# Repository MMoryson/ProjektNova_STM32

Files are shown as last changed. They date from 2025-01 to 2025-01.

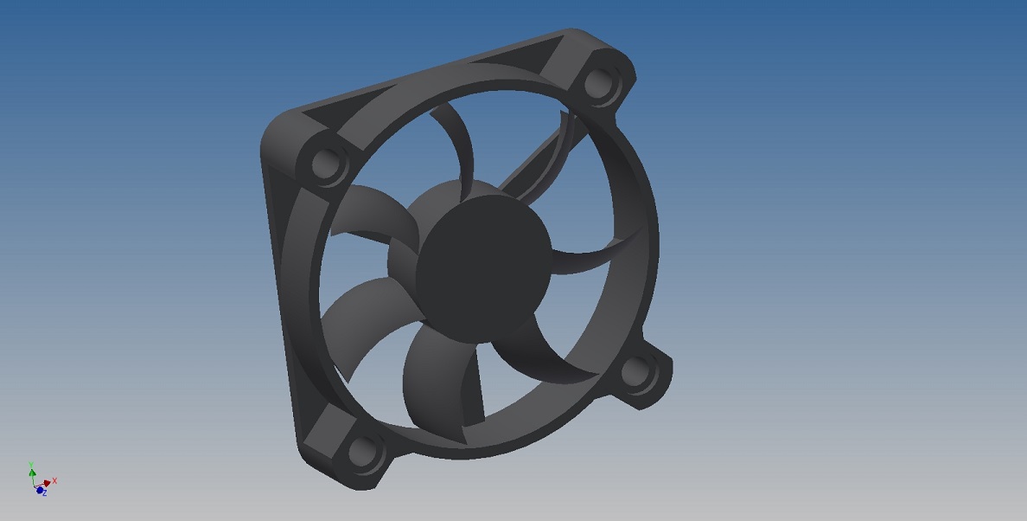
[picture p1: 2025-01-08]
Projekt_STM_model_Inventor/50-mm-dc-fan-1.snapshot.2/JAMICO FAN 50X50X10.jpg

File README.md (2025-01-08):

# ProjektNova_STM32
Jest to projekt na zajęcia z Systemów Mikroprocesorowych w ramach studiów Automatyka i Robotyka na Politechnice Poznańskiej

Projekt ma na celu stowrzenia układu sterowania wysokością piłeczki ping pongowej w tubie za pomocą wiatraka.

Projekt jest stworzony na płytce NUCLEO-F746ZG (z mikrokontrolerem STM32F746ZG)
Użyte elementy:
- enkoder inkrementalny (20 impulsów na obrót)
- wyświetlacz ssd1306 oled komunikujący się za pomocą I2C 
- ultradźwiękowy hc-sr04
- tranzystor n mosfet tht irl540npbf (100 Vds)
- wiatrak (50x50mm, Napięcie: DC 5-12V, Prąd: 0.3A, RPM(11.1V): 3500, 50x50x10mm, 20g)
- zasilacz (9V/0.6A)
- kondensatory 10nF
- reyzstory 1.1 kOhmów i 10 kOhmów
- przewody

Projekt używa biblioteki z własnymi modyfikacjami do wyświetlacza ssd1306 zaczerpniętej z: https://github.com/ptrre/kurs-stm32-e18-oled-i2c .

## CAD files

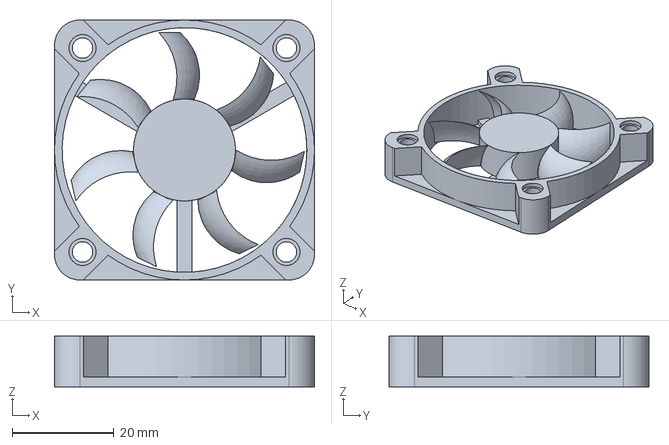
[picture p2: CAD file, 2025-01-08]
Projekt_STM_model_Inventor/50-mm-dc-fan-1.snapshot.2/JAMICO FAN 50X50X10.stp
51.0 x 51.0 x 10.0 mm

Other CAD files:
Projekt_STM_model_Inventor/50-mm-dc-fan-1.snapshot.2/JAMICO FAN 50X50X10.igs
Projekt_STM_model_Inventor/50-mm-dc-fan-1.snapshot.2/JAMICO FAN 50X50X10.ipt
Projekt_STM_model_Inventor/50-mm-dc-fan-1.snapshot.2/JAMICO FAN 50X50X10.x_b
Projekt_STM_model_Inventor/Calosc.iam
Projekt_STM_model_Inventor/CzujnikUltraDziekowy.iam
Projekt_STM_model_Inventor/enkoder.ipt

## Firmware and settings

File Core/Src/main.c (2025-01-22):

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
/* Includes ------------------------------------------------------------------*/
#include "main.h"
#include "dma.h"
#include "i2c.h"
#include "tim.h"
#include "usart.h"
#include "usb_otg.h"
#include "gpio.h"

/* USER CODE BEGIN Includes */
/*
 * Jest to regulator PI wiec:
 * sygnal refenercyjny - 	czyjnik			- dystans
 * sygnal wejsciowy - 		enkoder			- pozycja
 * sygnal wyjsciowy - 		wypelnienie pwm - wypelnienie
 */

#include <stdio.h>
#include <string.h>
#include "GFX.h"
#include "bitmapy.h"
#include "i2c_connection.h"
/* USER CODE END Includes */


/* USER CODE BEGIN PV */
uint8_t znak, komunikat[20];
uint16_t dl_kom;

//uint16_t wypelnienie = 0;
//temp
float wypelnienie = 0.0;
uint8_t pwm_send = 0;

char msg[64];

uint32_t counter;
int16_t count;
int16_t pozycja = 20;
int16_t pozycja_send=20;

char msg_dyst[64];
uint32_t pMillis;
uint32_t Value1 = 0;
uint32_t Value2 = 0;
uint16_t dystans  = 0;
uint16_t dystans_temp = 0;

uint32_t previousTime = 0;

typedef struct {
    float Kp;      // Wzmocnienie proporcjonalne
    float Ki;      // Wzmocnienie całkujące
    float calka; // Skumulowany błąd
    float zadana; // Wartość zadana
} Reg_PI;

Reg_PI nasz_PI = {
    .Kp = 13.5f,  // Ustawienia wzmocnienia
    .Ki = 0.48f,
    .calka = 0.0f,
    .zadana = 0.0f // Przykładowa wartość zadana
};

float dt = 0.0001f;
float wynik;
float wynik_temp;
float uchyb;
int ograniczenie_calki = 40;


/* USER CODE END PV */

void SystemClock_Config(void);
/* USER CODE BEGIN 0 */

void HAL_GPIO_EXTI_Callback(uint16_t GPIO_Pin)
{
	if(GPIO_Pin == P2_Pin)
	{
		HAL_GPIO_TogglePin(LD1_GPIO_Port, LD1_Pin);
		pozycja = pozycja_send;

		if (!stan_rozpoczecia_inwersji)
		{
			stan_rozpoczecia_inwersji = true;
			odliczenie_inwersji = HAL_GetTick();
			licznik_migniec = 0;
			stan_inwersji = false;
		}


		//SSD1306_display_invert(true);
		//HAL_Delay(10);
		//SSD1306_display_invert(false);
	}
	if (GPIO_Pin == Echo_Pin)
	{
		pMillis = HAL_GetTick();
		while (!(HAL_GPIO_ReadPin (Echo_GPIO_Port, Echo_Pin)) && pMillis + 10 >  HAL_GetTick());
		Value1 = __HAL_TIM_GET_COUNTER (&htim4);

		pMillis = HAL_GetTick();
		while ((HAL_GPIO_ReadPin (Echo_GPIO_Port, Echo_Pin)) && pMillis + 50 > HAL_GetTick());
		Value2 = __HAL_TIM_GET_COUNTER (&htim4);
		dystans_temp = 100 - (Value2-Value1)* 0.034/2;

		dystans = saturacja(dystans_temp, 0, 90);


		//dystans = dystans_temp;




		/*if(abs(dystans_temp - dystans)>100)
		{
			dystans = saturacja(dystans, 10, 100);
		}
		else{
			dystans = saturacja(dystans_temp, 10, 100);
		}*/

		/*
		int tx_msg_len_tim = sprintf((char *)msg_dyst, "dystans: %d cm\r\n", dystans);
		HAL_UART_Transmit(&huart3, (uint8_t *)msg_dyst, tx_msg_len_tim, 100);
		*/

	 }

}

void HAL_UART_RxCpltCallback(UART_HandleTypeDef *huart)
{
	if(huart->Instance == USART3)
	{

		int enkoder = strtol((char*)&znak, 0, 10);
		pozycja = saturacja(enkoder, 20, 100);
		pozycja_send = pozycja;

		//HAL_UART_Transmit_IT(&huart3, komunikat, dl_kom);
		HAL_UART_Receive_IT(&huart3, &znak, 3);

	}
}

int wrap_encoder(int count, int min, int max, int shift, TIM_HandleTypeDef *htim)
{
    if (count < min * 4) {
        count += (max - min) * 4;
        __HAL_TIM_SET_COUNTER(htim, count);
        return min;
    }
    if (count > max * 4) {
        count -= (max - min) * 4;
        __HAL_TIM_SET_COUNTER(htim, count);
        return max;
    }
    return count / 4 + shift;
}

void HAL_TIM_IC_CaptureCallback(TIM_HandleTypeDef *htim)
{

	//static uint32_t last_send_time = 0;

	counter = __HAL_TIM_GET_COUNTER(&htim3);
	count = (int16_t)counter;

	pozycja_send = wrap_encoder(count, 0, 80, 20, &htim3);

	/*if (HAL_GetTick() - last_send_time >= 100)
	{
		last_send_time = HAL_GetTick();
		uint8_t tx_buffer[32];
		int tx_msg_len = sprintf((char*)tx_buffer, "Encoder counter: %d\n\r", pozycja);
		HAL_UART_Transmit(&huart3, tx_buffer, tx_msg_len, 100);
	}*/

}

void czujnik_wysylanie(int time)
{
	HAL_GPIO_WritePin(Trigger_GPIO_Port, Trigger_Pin, GPIO_PIN_SET);
	__HAL_TIM_SET_COUNTER(&htim4, 0);
	while (__HAL_TIM_GET_COUNTER(&htim4) < time);
	HAL_GPIO_WritePin(Trigger_GPIO_Port, Trigger_Pin, GPIO_PIN_RESET);
}

int saturacja(int wartosc, int min, int max)
{

	if(wartosc > max)
	{
		wartosc = max;
	}
	if(wartosc < min)
	{
		wartosc = min;
	}
	return wartosc;
}

float obliczanie_PI(Reg_PI *regulator, float dystans, float dt, int ograniczenie) {
    // Obliczanie błędu
    uchyb = regulator->zadana - dystans;

    // Część całkująca
    regulator->calka += uchyb*dt;

    float P = regulator->Kp * uchyb;
    float I;
/*
    if (100*abs(uchyb)/regulator->zadana > ograniczenie)
    {
    	regulator->calka= 0;
    }
*/
    I = regulator->Ki * regulator->calka;

    return  P+I;
}

void HAL_TIM_PeriodElapsedCallback(TIM_HandleTypeDef *htim)
{
	if(htim == &htim14)
	{
		czujnik_wysylanie(10);
		nasz_PI.zadana = pozycja;
		wynik_temp = saturacja(obliczanie_PI(&nasz_PI, (float)dystans, dt, ograniczenie_calki),0, 999)+430.0f;

		wynik = saturacja(wynik_temp, 000, 999);
		wypelnienie = (uint16_t)wynik;
		pwm_send = (uint8_t)(100*wynik/999);
		__HAL_TIM_SET_COMPARE(&htim2, TIM_CHANNEL_1, wypelnienie);


	 	/*wypelnienie = 464;

		if( wypelnienie == 0){flag = 0;}
		if( wypelnienie == 998){flag = 1;}
		if(flag){wypelnienie = wypelnienie - 1;}
		else{wypelnienie = wypelnienie + 1;}
		//wypelnienie = wypelnienie + 1;
	 	  if (wypelnienie > 998){wypelnienie = 0;}
	 	  __HAL_TIM_SET_COMPARE(&htim2, TIM_CHANNEL_1, (uint16_t)wypelnienie);
	 	 pwm_send = (uint8_t)(100*wypelnienie/999);
	 	 */
	 	  //pwm_send = wypelnienie;

		  //temp
		 //pozycja = 60;
		 //pozycja_send = pozycja;


	}

}

/* USER CODE END 0 */

/**
  * @brief  The application entry point.
  * @retval int
  */
int main(void)
{

  /* USER CODE BEGIN 1 */
	//HAL_Delay(500);
  /* USER CODE END 1 */

  /* MCU Configuration--------------------------------------------------------*/

  /* Reset of all peripherals, Initializes the Flash interface and the Systick. */
  HAL_Init();

  /* Configure the system clock */
  SystemClock_Config();

  /* Initialize all configured peripherals */
  MX_GPIO_Init();
  MX_DMA_Init();
  MX_USART3_UART_Init();
  MX_USB_OTG_FS_PCD_Init();
  MX_TIM2_Init();
  MX_TIM3_Init();
  MX_I2C1_Init();
  MX_TIM4_Init();
  MX_TIM14_Init();
  /* USER CODE BEGIN 2 */
  HAL_UART_Receive_IT(&huart3, &znak, 3);

  HAL_TIM_PWM_Start(&htim2, TIM_CHANNEL_1);


  HAL_TIM_Encoder_Start_IT(&htim3, TIM_CHANNEL_ALL);
  __HAL_TIM_SET_COMPARE(&htim2, TIM_CHANNEL_1, 0);




  SSD1306_init();
  //GFX_draw_fill_rect(0, 0, 2*64, 2*32, BLACK);
  //GFX_draw_fill_rect(64, 32, 64, 32, WHITE);
  //GFX_draw_char(10, 10, 'a', WHITE, BLACK, 2, 2);
  //GFX_draw_string(0, 0, (unsigned char *)"Dupia", WHITE, BLACK, 2,2);
  //SSD1306_display_invert(true);
  //GFX_draw_Bitmap(0, 0, wiatrak1, 128, 64, WHITE, BLACK);
  //GFX_draw_string(0, 0, (unsigned char *)"Dupia", WHITE, BLACK, 2,2);
  //SSD1306_display_repaint();
  HAL_TIM_Base_Start_IT(&htim4);
  HAL_GPIO_WritePin(Trigger_GPIO_Port, Trigger_Pin, GPIO_PIN_RESET);
  HAL_TIM_Base_Start_IT(&htim14);




  /* USER CODE END 2 */

  /* Infinite loop */
  /* USER CODE BEGIN WHILE */
  while (1)
  {



	  inwersja3x();
	  oled(pozycja_send, dystans, pwm_send);


		 if (HAL_GetTick() - previousTime >= 500) // Sprawdź, czy minęło 500 ms
		    {
		        previousTime = HAL_GetTick(); // Zapisz aktualny czas

		        int tx_msg_len = sprintf((char *)msg_dyst, "Distance: %d cm, Pozycja: %d , PWM: %d , Encoder counter: %d \n\r", dystans, pozycja, pwm_send, pozycja_send);
		        HAL_UART_Transmit(&huart3, (uint8_t *)msg_dyst, tx_msg_len, 100);
		    }

		  HAL_Delay(10);


		  /*
		  //PWM
		 	  wypelnienie = wypelnienie + 1;
		 	  if (wypelnienie > 998){wypelnienie = 0;}
		 	  __HAL_TIM_SET_COMPARE(&htim2, TIM_CHANNEL_1, wypelnienie);
		 	  pwm_send = wypelnienie;
		 	  */

		/*
		 		int tx_msg_len_tim = sprintf((char *)msg_dyst, "dystans: %d cm\r\n", dystans);
		HAL_UART_Transmit(&huart3, (uint8_t *)msg_dyst, tx_msg_len_tim, 100);
		 if (HAL_GetTick() - last_send_time >= 100)
		 	{
		 		last_send_time = HAL_GetTick();
		 		uint8_t tx_buffer[32];
		 		int tx_msg_len = sprintf((char*)tx_buffer, "Encoder counter: %d\n\r", pozycja);
		 		HAL_UART_Transmit(&huart3, tx_buffer, tx_msg_len, 100);
		 	}*/


	  /*
	  if(HAL_GPIO_ReadPin(P2_GPIO_Port, P2_Pin))
		 {
			 HAL_Delay(10);
			 HAL_GPIO_TogglePin(LD2_GPIO_Port, LD2_Pin);
		 }
	  */

    /* USER CODE END WHILE */

    /* USER CODE BEGIN 3 */
  }
  /* USER CODE END 3 */
}

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


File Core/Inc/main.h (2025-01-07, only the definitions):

#define MCO_Pin GPIO_PIN_0
#define MCO_GPIO_Port GPIOH
#define RMII_MDC_Pin GPIO_PIN_1
#define RMII_MDC_GPIO_Port GPIOC
#define RMII_REF_CLK_Pin GPIO_PIN_1
#define RMII_REF_CLK_GPIO_Port GPIOA
#define RMII_MDIO_Pin GPIO_PIN_2
#define RMII_MDIO_GPIO_Port GPIOA
#define RMII_CRS_DV_Pin GPIO_PIN_7
#define RMII_CRS_DV_GPIO_Port GPIOA
#define RMII_RXD0_Pin GPIO_PIN_4
#define RMII_RXD0_GPIO_Port GPIOC
#define RMII_RXD1_Pin GPIO_PIN_5
#define RMII_RXD1_GPIO_Port GPIOC
#define LD1_Pin GPIO_PIN_0
#define LD1_GPIO_Port GPIOB
#define Trigger_Pin GPIO_PIN_12
#define Trigger_GPIO_Port GPIOF
#define Echo_Pin GPIO_PIN_13
#define Echo_GPIO_Port GPIOF
#define Echo_EXTI_IRQn EXTI15_10_IRQn
#define RMII_TXD1_Pin GPIO_PIN_13
#define RMII_TXD1_GPIO_Port GPIOB
#define LD3_Pin GPIO_PIN_14
#define LD3_GPIO_Port GPIOB
#define STLK_RX_Pin GPIO_PIN_8
#define STLK_RX_GPIO_Port GPIOD
#define STLK_TX_Pin GPIO_PIN_9
#define STLK_TX_GPIO_Port GPIOD
#define USB_PowerSwitchOn_Pin GPIO_PIN_6
#define USB_PowerSwitchOn_GPIO_Port GPIOG
#define USB_OverCurrent_Pin GPIO_PIN_7
#define USB_OverCurrent_GPIO_Port GPIOG
#define USB_SOF_Pin GPIO_PIN_8
#define USB_SOF_GPIO_Port GPIOA
#define USB_VBUS_Pin GPIO_PIN_9
#define USB_VBUS_GPIO_Port GPIOA
#define USB_ID_Pin GPIO_PIN_10
#define USB_ID_GPIO_Port GPIOA
#define USB_DM_Pin GPIO_PIN_11
#define USB_DM_GPIO_Port GPIOA
#define USB_DP_Pin GPIO_PIN_12
#define USB_DP_GPIO_Port GPIOA
#define TMS_Pin GPIO_PIN_13
#define TMS_GPIO_Port GPIOA
#define TCK_Pin GPIO_PIN_14
#define TCK_GPIO_Port GPIOA
#define P2_Pin GPIO_PIN_7
#define P2_GPIO_Port GPIOD
#define P2_EXTI_IRQn EXTI9_5_IRQn
#define RMII_TX_EN_Pin GPIO_PIN_11
#define RMII_TX_EN_GPIO_Port GPIOG
#define RMII_TXD0_Pin GPIO_PIN_13
#define RMII_TXD0_GPIO_Port GPIOG
#define SW0_Pin GPIO_PIN_3
#define SW0_GPIO_Port GPIOB
#define LD2_Pin GPIO_PIN_7
#define LD2_GPIO_Port GPIOB

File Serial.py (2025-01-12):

import csv
import serial
import re
import time
import matplotlib.pyplot as plt
from collections import deque
import tkinter as tk
from tkinter import messagebox

# Flaga globalna do przerwania pętli
stop_plotting = False

# Funkcja do odczytu danych z UART
def odczyt_uart(csv_plik, port='COM3', baudrate=115200, timeout=1):
    start = time.time()
    ser = serial.Serial(port, baudrate, timeout=timeout)

    with open(csv_plik, mode='w', newline='') as file:
        writer = csv.writer(file)
        writer.writerow(['Czas', 'Dystans', 'Pozycja', 'PWM', 'Enkoder'])

    last_time = -1  # Zmienna do sprawdzania unikalności czasu

    try:
        while True:
            if ser.in_waiting > 0:
                a = round(time.time() - start, 3)  # Zaokrąglanie czasu do 3 miejsc po przecinku
                if a == last_time:
                    continue  # Pomijanie duplikatów czasu
                last_time = a

                line = ser.readline().decode('utf-8', errors='ignore').strip()
                temp = re.findall(r'\d+', line)
                res = list(map(int, temp))
                if temp:
                    dystans = res[0]
                    pozycja = res[1]
                    pwm = res[2]
                    enkoder = res[3]
                    czas = a
                    with open(csv_plik, mode='a', newline='') as file:
                        writer = csv.writer(file)
                        writer.writerow([czas, dystans, pozycja, pwm, enkoder])
                    yield (czas, dystans, pozycja, pwm, enkoder)
    except KeyboardInterrupt:
        print("Zatrzymanie zbierania danych.")
    finally:
        if ser.is_open:
            ser.close()
        print("Zamknięto port UART.")

# Funkcja główna do rysowania wykresu
def plot_data(csv_plik, plot_dystans, plot_pozycja, plot_pwm, plot_enkoder):
    global stop_plotting
    uart_data = odczyt_uart(csv_plik)

    czas_list = deque(maxlen=100)
    dystans_list = deque(maxlen=100)
    pozycja_list = deque(maxlen=100)
    pwm_list = deque(maxlen=100)
    enkoder_list = deque(maxlen=100)

    # Tworzenie wykresu
    fig, ax = plt.subplots(figsize=(8, 6))

    def on_close(event):
        """Callback, gdy okno wykresu jest zamykane."""
        global stop_plotting
        stop_plotting = True
        plt.close(fig)  # Zamknięcie okna matplotlib

    fig.canvas.mpl_connect('close_event', on_close)  # Rejestracja zdarzenia zamknięcia

    try:
        while not stop_plotting:
            czas, dystans, pozycja, pwm, enkoder = next(uart_data)
            czas_list.append(czas)
            dystans_list.append(dystans)
            pozycja_list.append(pozycja)
            pwm_list.append(pwm)
            enkoder_list.append(enkoder)

            ax.clear()
            ax.grid(True)

            if plot_dystans:
                ax.plot(czas_list, dystans_list, label='Dystans', color='blue')
            if plot_pozycja:
                ax.plot(czas_list, pozycja_list, label='Pozycja', color='red')
            if plot_pwm:
                ax.plot(czas_list, pwm_list, label='PWM', color='green')
            if plot_enkoder:
                ax.plot(czas_list, enkoder_list, label='Enkoder', color='red')

            ax.set_xlabel('Czas [s]')
            ax.set_ylabel('Wartości')
            ax.legend()

            ax.text(0.5, 1.0, f"Dystans: {dystans_list[-1] if dystans_list else '--'} cm, Enkoder: {enkoder_list[-1] if enkoder_list else '--'}",
                    transform=ax.transAxes, fontsize=12, ha='center', va='bottom', color='blue')

            plt.pause(0.1)
    except KeyboardInterrupt:
        print("Przerwano przez użytkownika.")
    except StopIteration:
        print("Brak więcej danych do odczytu.")
    finally:
        plt.close(fig)
        print("Zamknięto wykres.")

# Funkcja do wyboru opcji przed uruchomieniem wykresu
def choose_plot_options():
    def start_plot():
        plot_dystans = var_dystans.get()
        plot_pozycja = var_pozycja.get()
        plot_pwm = var_pwm.get()
        plot_enkoder = var_enkoder.get()

        if not plot_dystans and not plot_pozycja:
            messagebox.showerror("Błąd", "Musisz wybrać przynajmniej jedną zmienną do wykresu.")
        else:
            root.destroy()  # Zamknięcie okna wyboru
            plot_data("data.csv", plot_dystans, plot_pozycja, plot_pwm, plot_enkoder)

    root = tk.Tk()
    root.title("Wybór danych do wykresu")

    var_dystans = tk.BooleanVar(value=True)
    var_pozycja = tk.BooleanVar(value=True)
    var_pwm = tk.BooleanVar(value=True)
    var_enkoder = tk.BooleanVar(value=False)

    tk.Label(root, text="Wybierz dane do wykresu:").pack()
    tk.Checkbutton(root, text="Dystans", variable=var_dystans).pack()
    tk.Checkbutton(root, text="Pozycja", variable=var_pozycja).pack()
    tk.Checkbutton(root, text="PWM", variable=var_pwm).pack()
    tk.Button(root, text="Uruchom wykres", command=start_plot).pack()

    root.mainloop()

# Uruchomienie programu
if __name__ == "__main__":
    choose_plot_options()

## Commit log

2025-01-08 Model do druku 3D z programu Inventor
    Model w programie Inventor zamodelowany przez nas, który posłużył do wydrukowania 3D obudowy całego projektu.
    [Calosc.iam, CzujnikUltraDziekowy.iam, JAMICO FAN 50X50X10.igs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]
2025-01-12 Dodanie regulatora PI, wysyłanie danych przez UART
    Dodanie samego w sobie regulatora PI, wysyłanie danych przez UART na takim samym poziomie, co przez fizyczny enkoder, proste odfiltrowanie danych z czujnika, dodanie funkcji pomocnycznych, dodanie zm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
2025-01-17 Połączenie z wyswietlaczem przez i2c
    Drobne zmiany, rózne testy regulatora, głównie połączenie i2c z wyswietlaczem
2025-01-22 Regulacja, końcowe poprawki, kod do matlaba
    Kod w c po przeprowadzeniu regulacji metodą Zieglera – Nicholsa i ręcznym doregulowaniu, poradzenie sobie z problemem nieczułości wiatraka, inne poprawki i testy. Generowanie wykresów w programie Matlab na podstawie zapisanych danych.
    [main.c]

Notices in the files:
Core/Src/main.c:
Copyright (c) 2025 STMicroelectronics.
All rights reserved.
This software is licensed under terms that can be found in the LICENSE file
